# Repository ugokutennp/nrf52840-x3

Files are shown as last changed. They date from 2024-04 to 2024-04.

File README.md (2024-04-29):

# nrf52840-x3
DIY Multiple Connection Watchman Dongle for SteamVR
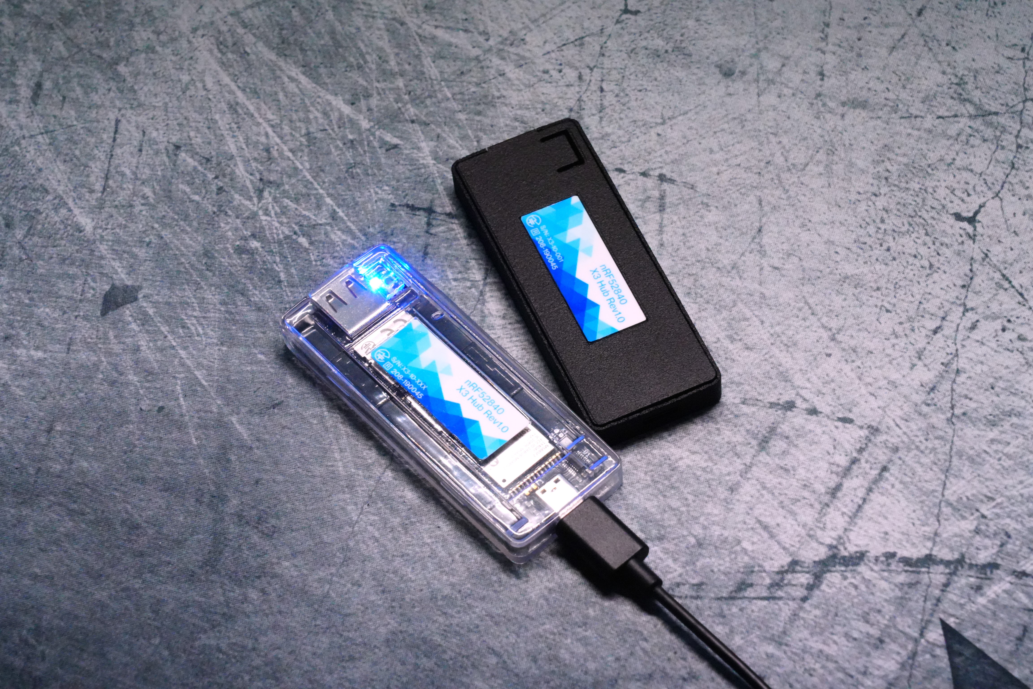
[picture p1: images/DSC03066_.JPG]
dongle


## Hardware
It includes data for PCBs made with Kicad7, Gerber data for manufacturing, 3D models of cases, and labels.   
USB2.0 Hub chip with four downstream ports (SL2.1s) running three nrf52840 (MS88SF2) and one USB Type A connector.

BOM can be viewed [here](https://htmlpreview.github.io/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).Other data are below.

[schematic](images/schematic.pdf),
[layout](images/Layout.png)

## Bootloader

The hex file in the Bootloader file is a build of [Adafruit_nRF52_Bootloader](https://github.com/adafruit/Adafruit_nRF52_Bootloader).
Using J-Link to write the bootloader via SWD, the uf2 firmware created with [Watchman-uf2](https://github.com/ugokutennp/watchman-uf2) can be written via USB.

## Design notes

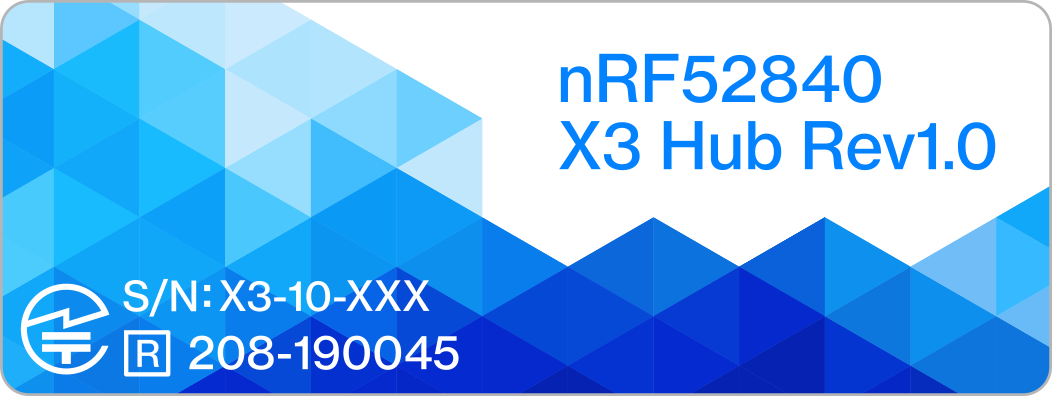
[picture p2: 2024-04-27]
Hardware/Label/Label.png

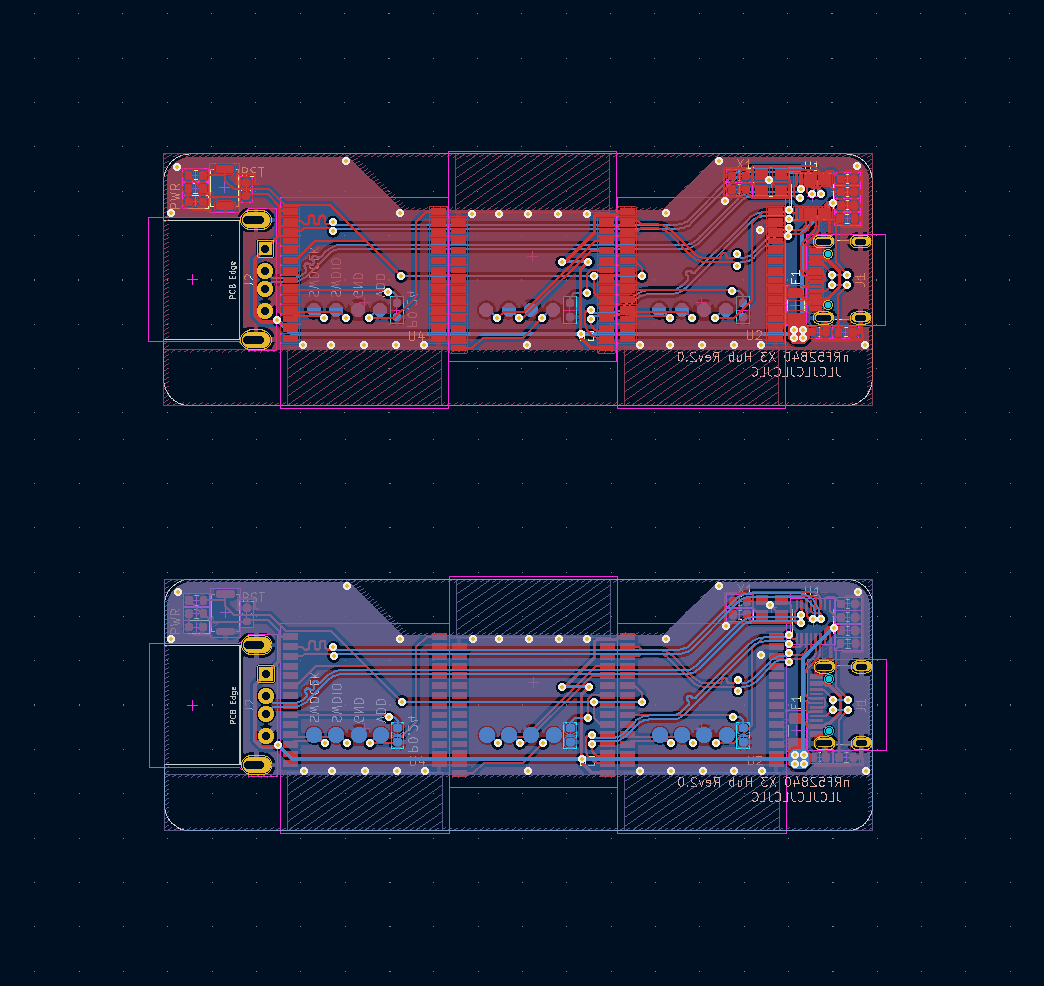
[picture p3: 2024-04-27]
images/Layout.png

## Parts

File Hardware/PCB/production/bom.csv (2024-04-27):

Designator | Footprint | Quantity | Value | LCSC Part #
_12, _11, _10, _9, _8, _7, _6, _5, _4, _3, _2, |  | 12
C1, C3, C4 | 0603 | 3 | 10u
C2 | 0603 | 1 | 100ｎ
D1 | 0603 | 1 | 19-217/BHC-ZL1M2RY/3T
F1 | 1206 | 1 | MF-NSMF050-2
J1 | HRO_TYPE-C-31-M-12 | 1 | TYPE-C-31-M-12
J2 | USB_A_U-A-24DD-W-16 | 1 | U-A-24DD-W-16
R1, R2 | 0603 | 2 | 5k1
R4 | 0603 | 1 | 470
R5 | 0603 | 1 | 10k
SW1 | SW_Push_SPST_NO_Alps_SKRK | 1 | SKRKAEE020
U1 | SSOP-16_sl2.1s | 1 | SL2.1S
U2, U3, U4 | XCVR_MS88SF2 | 3 | MS88SF2
X1 | Crystal_SMD_3225-4Pin_3.2x2.5mm | 1 | X322512MSB4SI

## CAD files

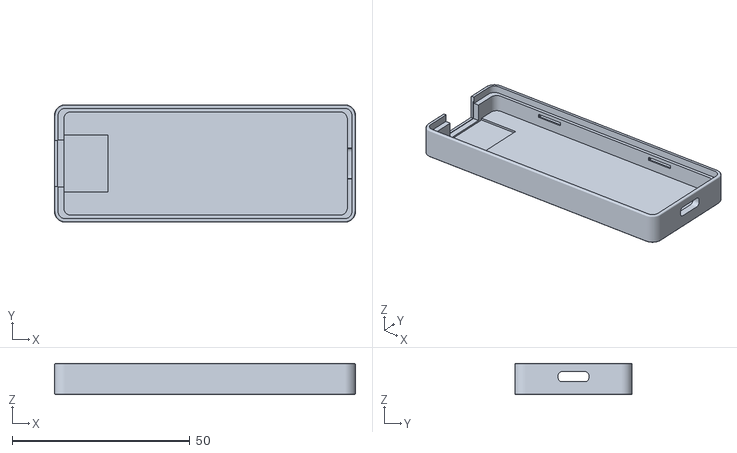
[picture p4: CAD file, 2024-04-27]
Hardware/Case/case_bottom.stl
84.6 x 33.0 x 8.72

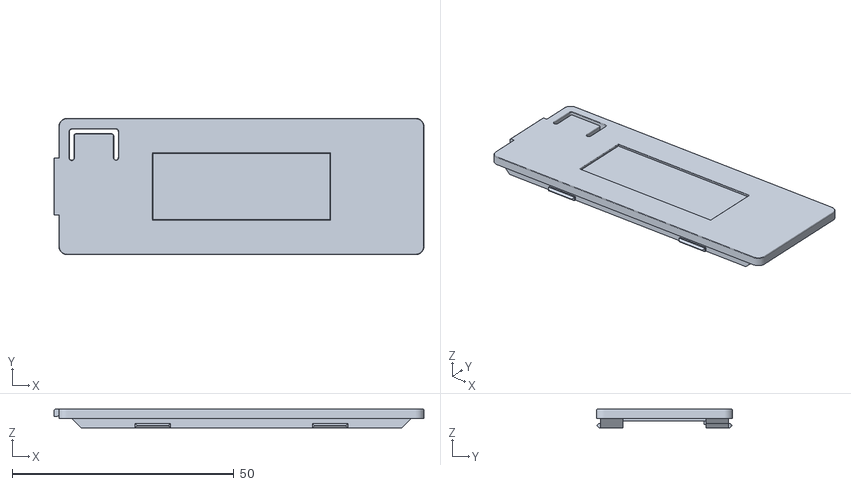
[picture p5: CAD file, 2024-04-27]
Hardware/Case/case_top.stl
83.5 x 30.8 x 4.20

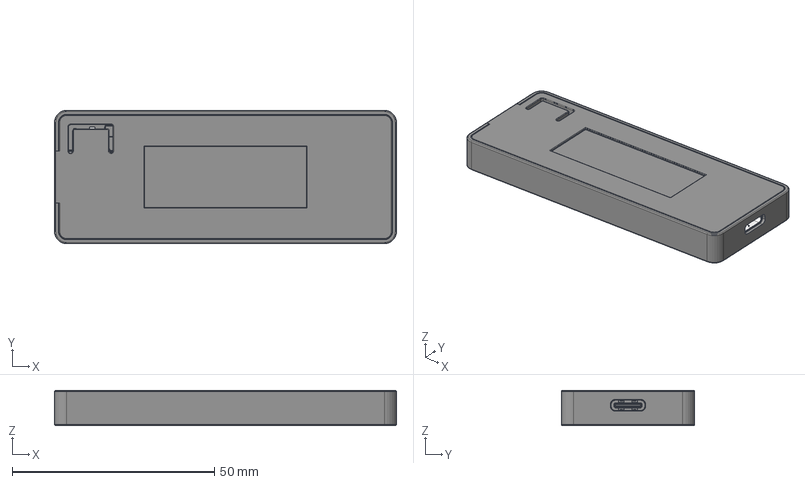
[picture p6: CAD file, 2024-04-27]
Hardware/Case/nrf52840_x3.step
84.6 x 33.0 x 8.72 mm
Pcb_dff
PCB_Sketch_dff
Board x 3
ant-2g4-03mL(1) x 3
epson2016 x 3
2012crystal x 3
ms88sf1 x 3
U6_SOT_666_dff39369cfeb x 2
C7_C_0402_1005Metric_ba1852a861b9 x 6
X1_Crystal_SMD_3225-4Pin_3.2x2.5mm_9aae7acbddef
SW1_SW_SPST_B3U-1000P_f7512aa61e6e[2]
R1_R_0402_1005Metric_de07fba90701 x 5
TYPE-C-31-M-12
TYPE-C-31-M-013
TYPE-C-31-M-014
TYPE-C-31-M-015
TYPE-C-31-M-016
TYPE-C-31-M-017
TYPE-C-31-M-018
TYPE-C-31-M-019
TYPE-C-31-M-020
TYPE-C-31-M-021
TYPE-C-31-M-022
TYPE-C-31-M-023
TYPE-C-31-M-024
TYPE-C-31-M-025
TYPE-C-31-M-026
TYPE-C-31-M-027
TYPE-C-31-M-028
TYPE-C-31-M-029
TYPE-C-31-M-030
TYPE-C-31-M-031
TYPE-C-31-M-032
TYPE-C-31-M-033
TYPE-C-31-M-034
TYPE-C-31-M-035
TYPE-C-31-M-036
TYPE-C-31-M-037
TYPE-C-31-M-038
TYPE-C-31-M-039
TYPE-C-31-M-040
TYPE-C-31-M-041
TYPE-C-31-M-042
TYPE-C-31-M-043
TYPE-C-31-M-044
TYPE-C-31-M-045
TYPE-C-31-M-046
TYPE-C-31-M-047
TYPE-C-31-M-048
TYPE-C-31-M-049
TYPE-C-31-M-050
TYPE-C-31-M-051
TYPE-C-31-M-052
TYPE-C-31-M-053
F1_Fuse_1206_3216Metric_4c27874a4316
D1_LED_0603_1608Metric_78edb89d3baf
U1_UCBGA_81_4x4mm_Layout9x9_P04mm_910c329b78b1[2]
FB1_L_0402_1005Metric_ed41ae4be7b0
C3_CP_EIA_3528_21_Kemet_B_16f031fefb57
USB_A_TE_292303-7_Horizontal

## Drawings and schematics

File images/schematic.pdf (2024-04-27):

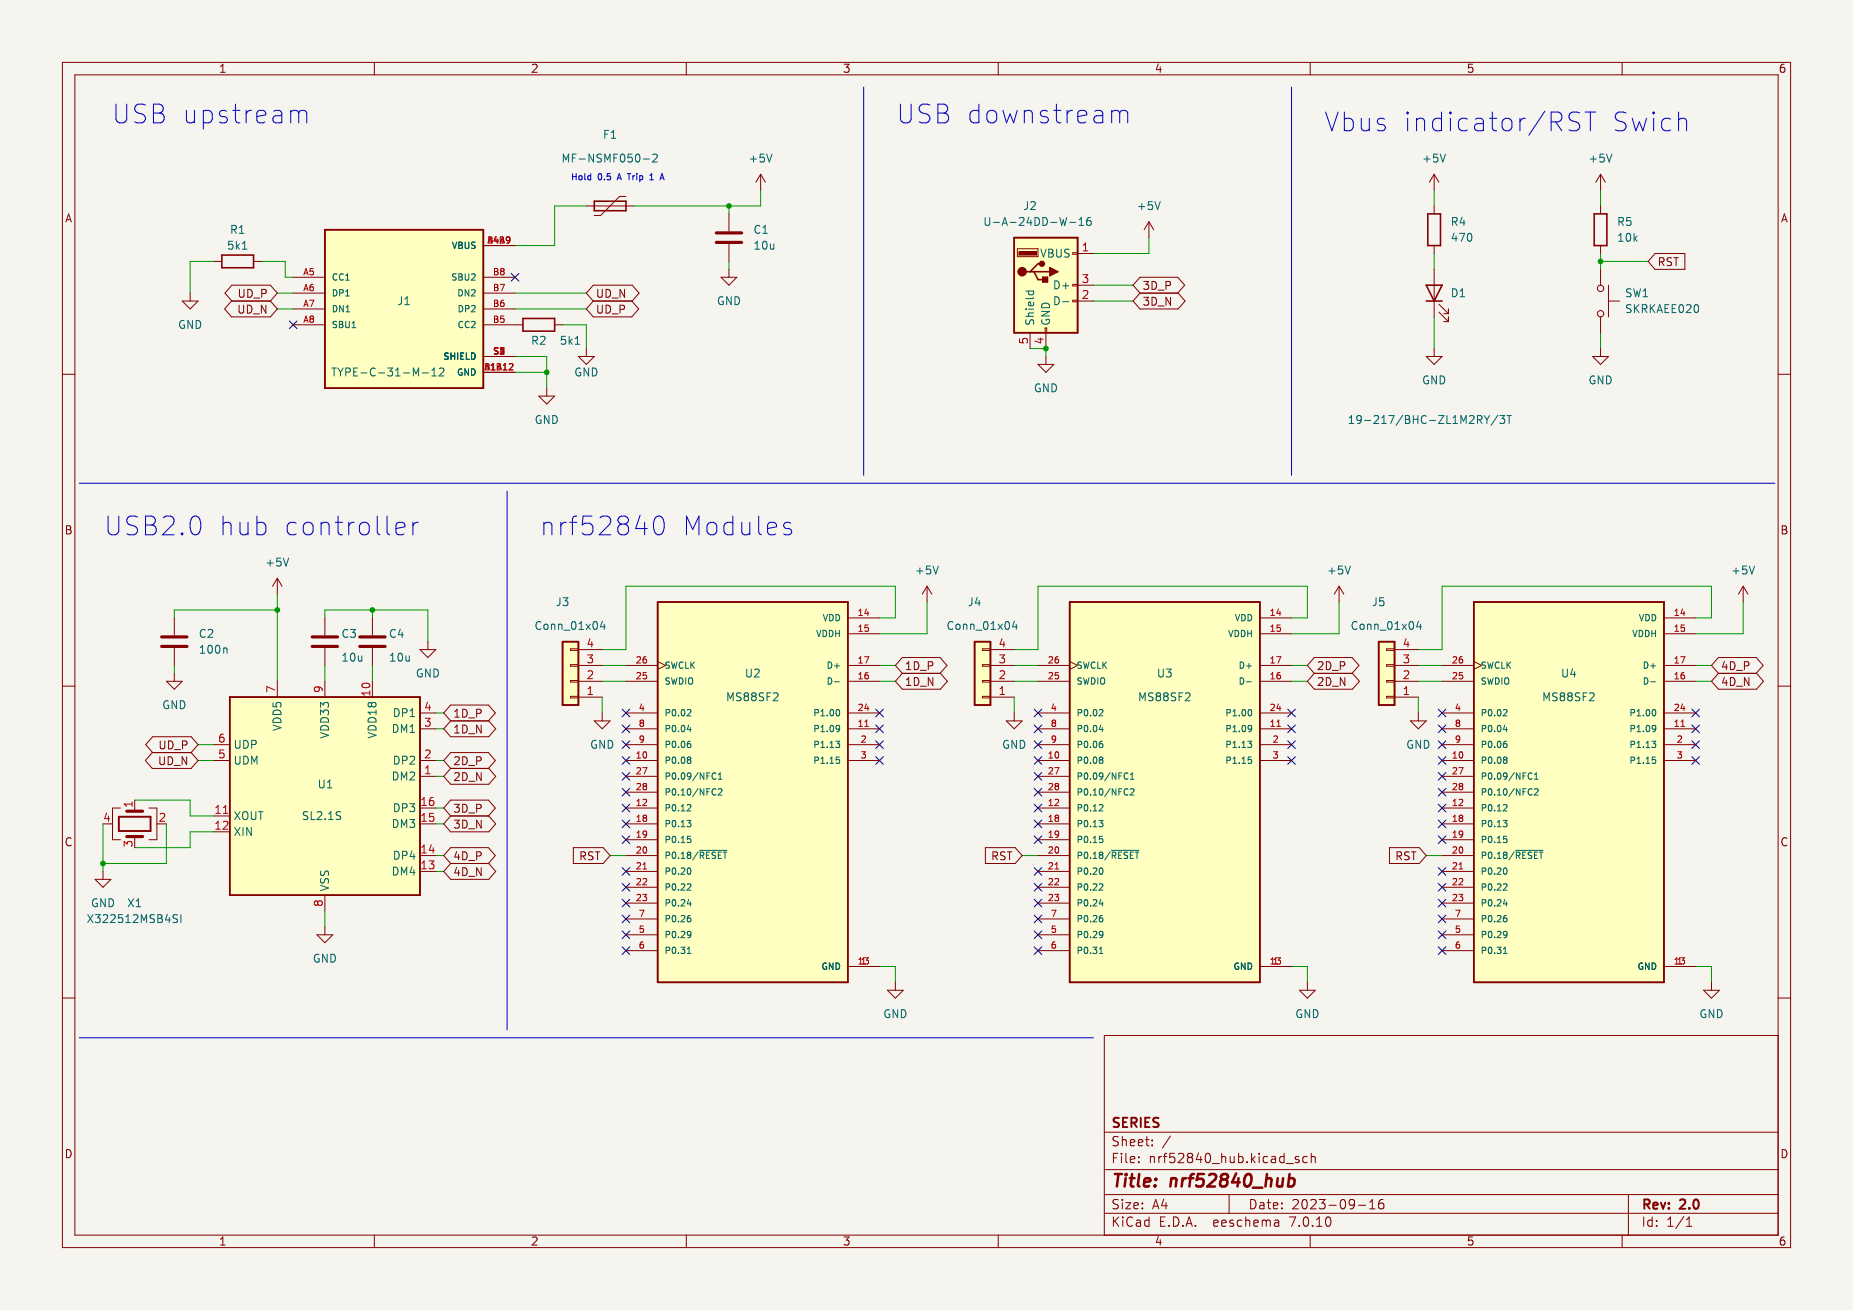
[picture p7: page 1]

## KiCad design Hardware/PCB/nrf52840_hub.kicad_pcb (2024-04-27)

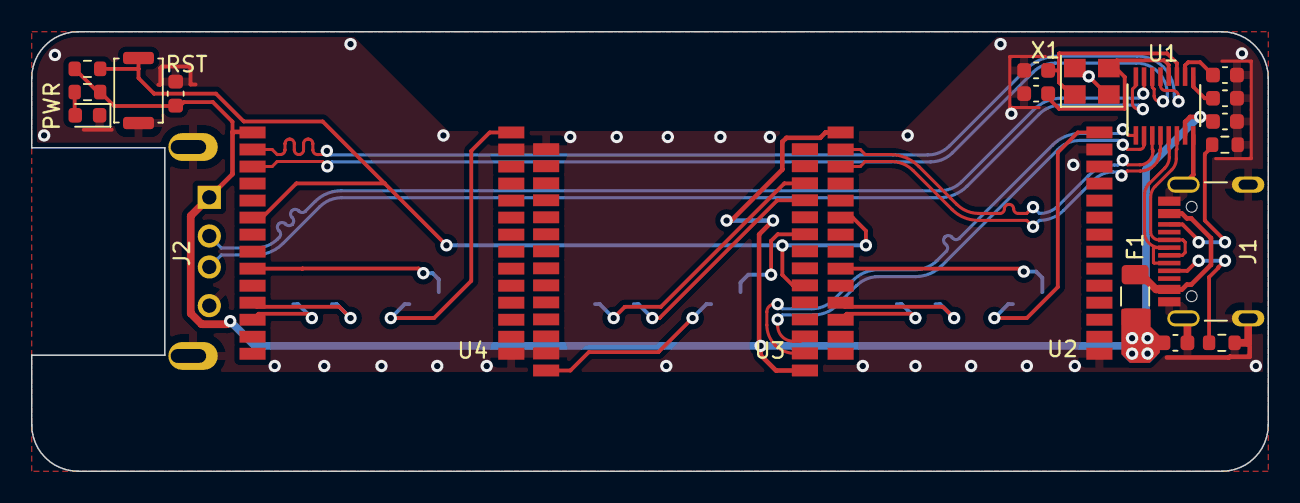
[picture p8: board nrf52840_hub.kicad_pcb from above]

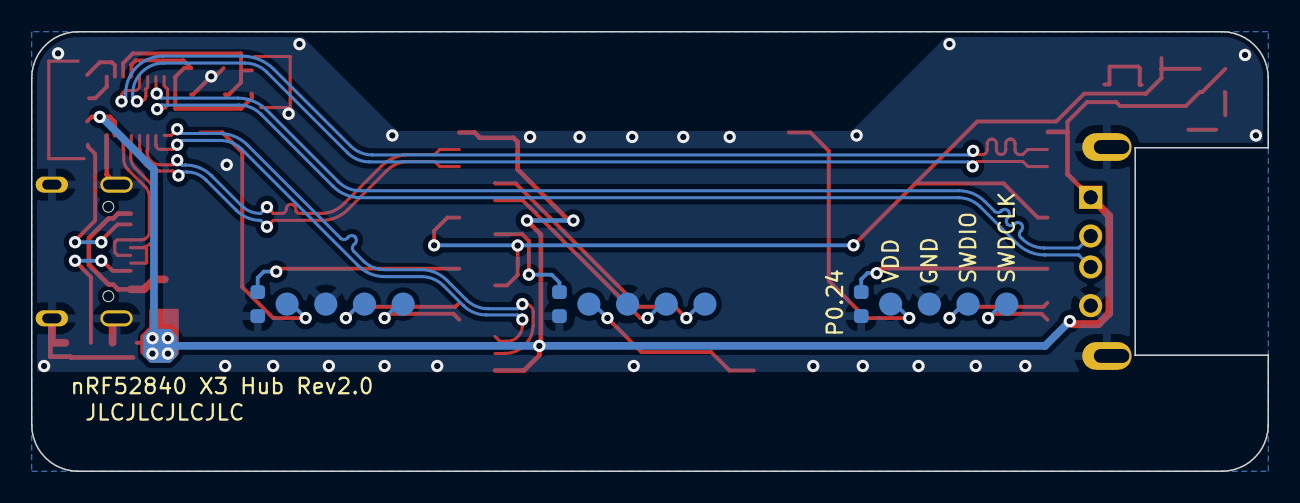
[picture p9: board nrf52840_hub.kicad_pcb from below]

Board: 2 copper layers, 79.9 x 28.4 mm, 21 parts (3 on the bottom side), 21 nets.

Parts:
C1, C3, C4: 10u; C_0603_1608Metric
C2: 100ｎ; C_0603_1608Metric
D1: 19-217/BHC-ZL1M2RY/3T; LED_0603_1608Metric
F1: MF-NSMF050-2; Fuse_1206_3216Metric
J1: TYPE-C-31-M-12; HRO_TYPE-C-31-M-12
J2: U-A-24DD-W-16; USB_A_U-A-24DD-W-16
R1, R2: 5k1; R_0603_1608Metric
R4: 470; R_0603_1608Metric
R5: 10k; R_0603_1608Metric
SW1: SKRKAEE020; SW_Push_SPST_NO_Alps_SKRK
U1: SL2.1S; SSOP-16_sl2.1s
U2, U3, U4: MS88SF2; XCVR_MS88SF2
X1: X322512MSB4SI; Crystal_SMD_3225-4Pin_3.2x2.5mm
p0.24, p0.24#2, p0.24#3: C_0603_1608Metric

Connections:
1D_N: U1.3 (DM1), U2.16 (D-)
1D_P: U1.4 (DP1), U2.17 (D+)
2D_N: U1.1 (DM2), U3.16 (D-)
2D_P: U1.2 (DP2), U3.17 (D+)
3D_N: J2.2 (D-), U1.15 (DM3)
3D_P: J2.3 (D+), U1.16 (DP3)
4D_N: U1.13 (DM4), U4.16 (D-)
4D_P: U1.14 (DP4), U4.17 (D+)
+5V: C1.1, C2.1, F1.2, J2.1 (VBUS), R4.1, R5.2, U1.7 (VDD5), U2.15 (VDDH), U3.15 (VDDH), U4.15 (VDDH)
GND: C1.2, C2.2, C3.1, C4.1, D1.1 (K), J1.A1B12 (GND), J1.B1A12 (GND), J1.S1 (SHIELD), J1.S2 (SHIELD), J1.S3 (SHIELD), J1.S4 (SHIELD), J2.4 (GND), J2.5 (Shield), R1.2, R2.2, SW1.2, U1.8 (VSS), U2.1 (GND), U2.13 (GND), U3.1 (GND), U3.13 (GND), U4.1 (GND), U4.13 (GND), X1.2, X1.4, p0.24.1, p0.24#2.1, p0.24#3.1
unnamed: C3.2, U1.9 (VDD33)
unnamed: C4.2, U1.10 (VDD18)
unnamed: D1.2 (A), R4.2
unnamed: F1.1, J1.A4B9 (VBUS), J1.B4A9 (VBUS)
unnamed: J1.A5 (CC1), R1.1
unnamed: J1.B5 (CC2), R2.1
unnamed: U1.11 (XOUT), X1.1
unnamed: U1.12 (XIN), X1.3
RST: R5.1, SW1.1, U2.20 (P0.18/~RESET), U3.20 (P0.18/~RESET), U4.20 (P0.18/~RESET)
UD_N: J1.A7 (DN1), J1.B7 (DN2), U1.5 (UDM)
UD_P: J1.A6 (DP1), J1.B6 (DP2), U1.6 (UDP)

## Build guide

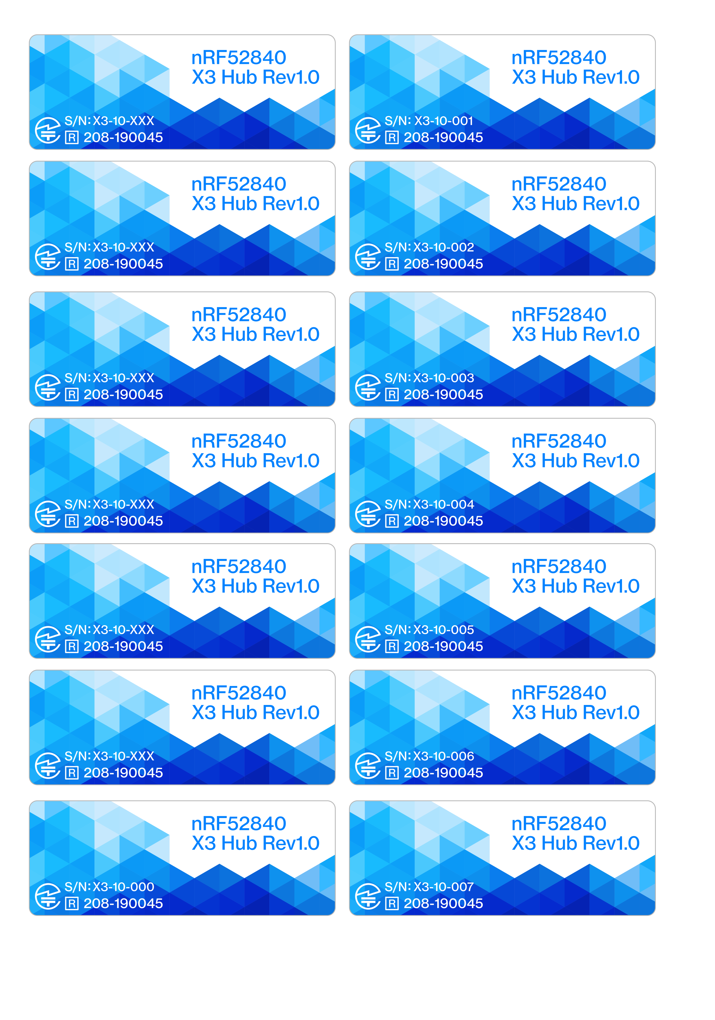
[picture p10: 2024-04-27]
Hardware/Label/Print.png
